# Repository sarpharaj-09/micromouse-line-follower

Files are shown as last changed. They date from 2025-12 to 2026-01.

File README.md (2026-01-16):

# Micromouse Line Follower

 **Project Status: In Development** 

A line-following micromouse robot project combining hardware design (KiCAD PCB layouts) with firmware development. This repository includes both Arduino Nano and ESP32 implementations, with comprehensive testing code and calibration tools.

## Overview

This project aims to build a reliable line-following robot using:
- **QTR-8 sensor array** for line detection
- **TB6612FNG motor driver** for motor control
- **Maze solving algorithm** with path simplification
- **PID control** for stable line following
- Dual MCU support: **ESP32** (primary) and **Arduino Nano** (testing)

The firmware includes motor control, PID tuning, sensor calibration, and a maze-solving algorithm that records and simplifies paths.

## Hardware

### Microcontrollers
- **ESP32 Development Board** (primary target)
- **Arduino Nano** (for testing and prototyping)

### Components
- **Motor Driver**: TB6612FNG
- **Line Sensors**: QTR-8 analog/RC sensor array
- **Motors**: DC motors for wheels
- **Power**: Battery pack
- **Display**: DM-OLED096 (0.96" OLED) - in design
- **Miscellaneous**: Jumper wires, resistors, capacitors

## Project Structure

```
micromouse-line-follower/
 Arduino_Nano/               # Arduino Nano PCB design (KiCAD)
    pcb_v1/                # Version 1 PCB layout
        DM-OLED096-636/    # OLED display footprint & symbol
        ESP32-DEVKIT-V1/   # ESP32 footprint & symbol
        MP1584_buck/       # Buck converter module
        kikad_dsign.*      # KiCAD project files
 ESP32/                      # ESP32 PCB design (KiCAD)
    pcb_v1/                # Version 1 PCB layout
        DM-OLED096-636/    # OLED display footprint & symbol
        ESP32-DEVKIT-V1/   # ESP32 footprint & symbol
        lineMazeSolver.*   # KiCAD project files
 micromouse_v1/             # Main firmware project (PlatformIO)
    micromouse_v1/
        platformio.ini     # PlatformIO configuration
        include/           # Header files
        lib/               # Dependencies (QTRSensors, TB6612FNG)
        src/
           main.cpp       # Main firmware with maze solving & PID
        test/              # Unit tests
 testing_phase_code/        # Standalone test sketches
    ESP32_test_code/       # ESP32-specific tests
       qtrSensor.ino     # QTR sensor test
    Nano_test_code/        # Arduino Nano tests
        Moter_test/        # Motor driver tests
        PID_Bluethooth/    # Bluetooth PID tuning
        plotter/           # Serial plotter data
        QTR_test/          # QTR sensor calibration
 README.md
```

## Firmware Features

### Current Implementation (main.cpp)
- **8-channel QTR sensor** integration with calibration
- **PID-based line following** with configurable gains (Kp, Kd)
- **Maze solving algorithm** with wall detection and path recording
- **Path simplification** to optimize shortest route
- **Motor control** with variable speed and direction
- **Turn decision logic** (left, straight, right)

### Pin Configuration (Arduino Nano)
```
Motor Control:
  - Motor 1: AIN1=4, AIN2=5, PWMA=3
  - Motor 2: BIN1=8, BIN2=9, PWMB=6
Control:
  - Switches: SW1=10, SW2=11, SW3=12
  - LED: 7
```

## Getting Started

### Prerequisites

- [PlatformIO](https://platformio.org/) (for ESP32 development)
- [Arduino IDE](https://www.arduino.cc/en/software) (for Nano sketches)
- Required libraries:
  - `SparkFun_TB6612` (Motor Driver)
  - `QTRSensors` (Line Sensor Array)

### Building & Uploading (PlatformIO/ESP32)

```powershell
cd micromouse_v1/micromouse_v1
pio run              # Build
pio run -t upload    # Upload to connected ESP32
```

### Testing (Arduino Nano)

1. Open Arduino IDE
2. Load a test sketch: `testing_phase_code/Nano_test_code/<test_folder>/<sketch>.ino`
3. Install dependencies via Library Manager
4. Select board (Arduino Nano) and COM port
5. Upload

### Test Sketches Available

| Sketch | Purpose |
|---|---|
| `Moter_test` | Test TB6612 motor driver (forward, backward, turn) |
| `QTR_test` | Read raw QTR sensor values and calibrate |
| `PID_Bluethooth` | Wireless PID tuning via Bluetooth serial |
| `plotter` | Stream sensor data for Serial Plotter visualization |

## Development Workflow

- **Feature branches**: Use `wip/*` prefix for work-in-progress branches
- **Main branch**: Keep stable with tested, documented commits
- **Testing**: Validate on both hardware and in simulation before merging
- **Documentation**: Update this README and code comments when adding features

## PCB Design Status

- **Arduino Nano v1**: In design phase - includes OLED display, buck converter
- **ESP32 v1**: In design phase - primary development board layout

## Troubleshooting

### Sensor Calibration Issues
- Run `QTR_test` to verify raw sensor values
- Check sensor array alignment over the line
- Verify power supply voltage (QTR operates 3.3-5V)

### Motor Control Issues
- Use `Moter_test` to verify TB6612 pin connections
- Check PWM pins are available on your MCU
- Verify motor power supply is adequate

### PID Tuning
- Use `PID_Bluethooth` for real-time parameter adjustment
- Start with low Kp/Kd values and increase gradually
- Monitor motor oscillation and response time

## Contributing

Contributions welcome! Please:
1. Create a feature branch (`wip/feature-name`)
2. Test thoroughly on hardware
3. Submit a pull request with clear description
4. Update documentation as needed

## License

This project is licensed under the terms specified in `LICENSE`.

---

**Last Updated**: January 2026  
**Note**: This project is actively developed. Features and documentation are updated frequently.

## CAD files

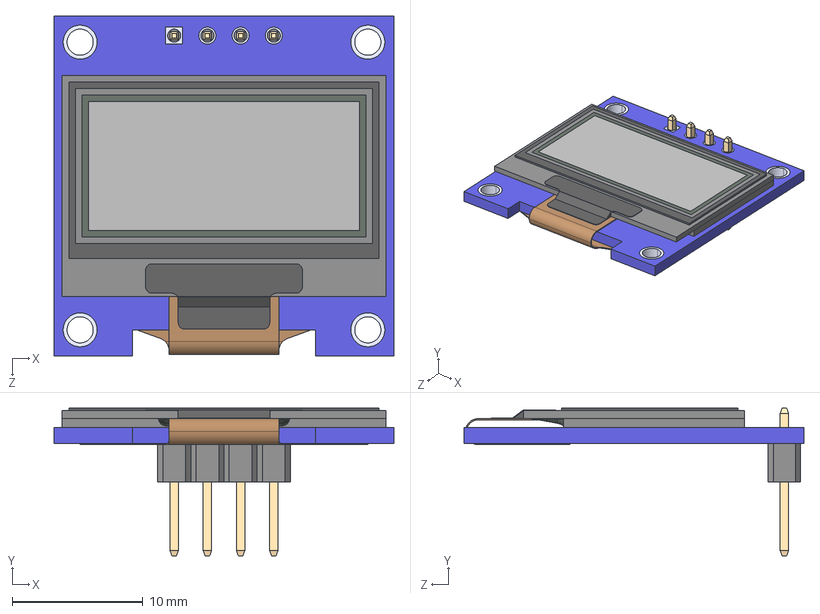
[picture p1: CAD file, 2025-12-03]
Arduino_Nano/pcb_v1/DM-OLED096-636--3DModel-STEP-56544.STEP
26.0 x 11.3 x 26.0 mm
DM-OLED096-636_Module
DM-OLED096-636_Panel

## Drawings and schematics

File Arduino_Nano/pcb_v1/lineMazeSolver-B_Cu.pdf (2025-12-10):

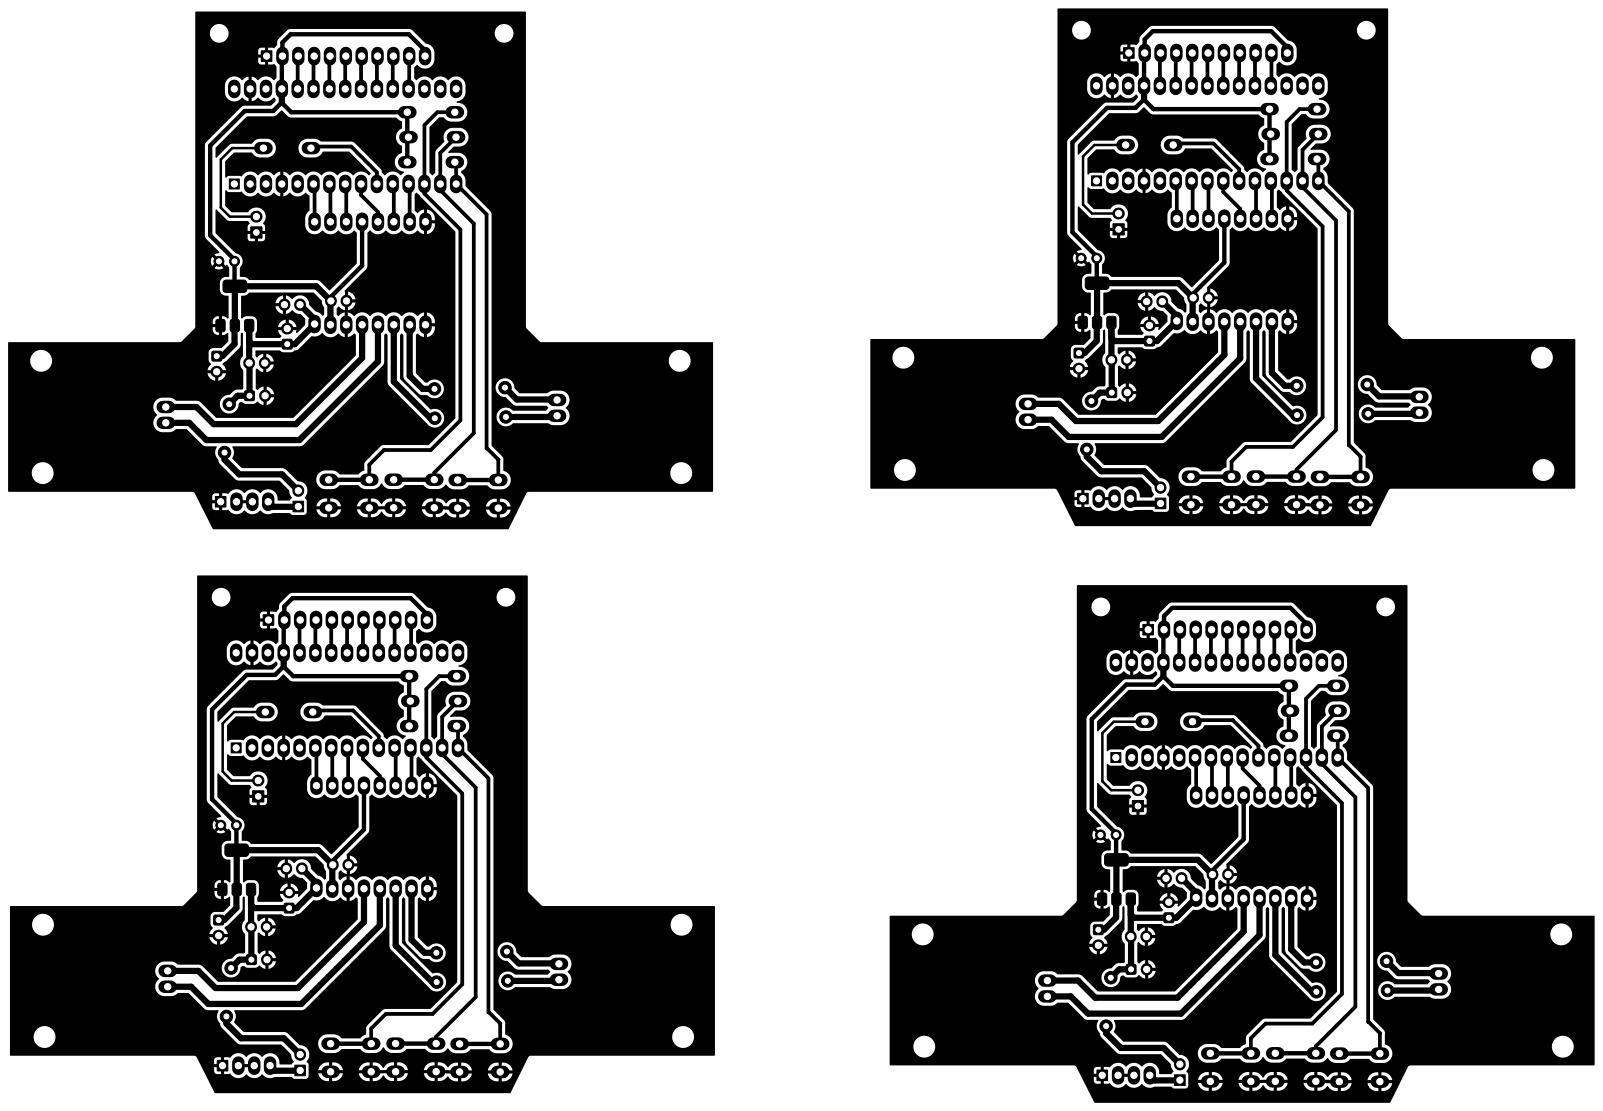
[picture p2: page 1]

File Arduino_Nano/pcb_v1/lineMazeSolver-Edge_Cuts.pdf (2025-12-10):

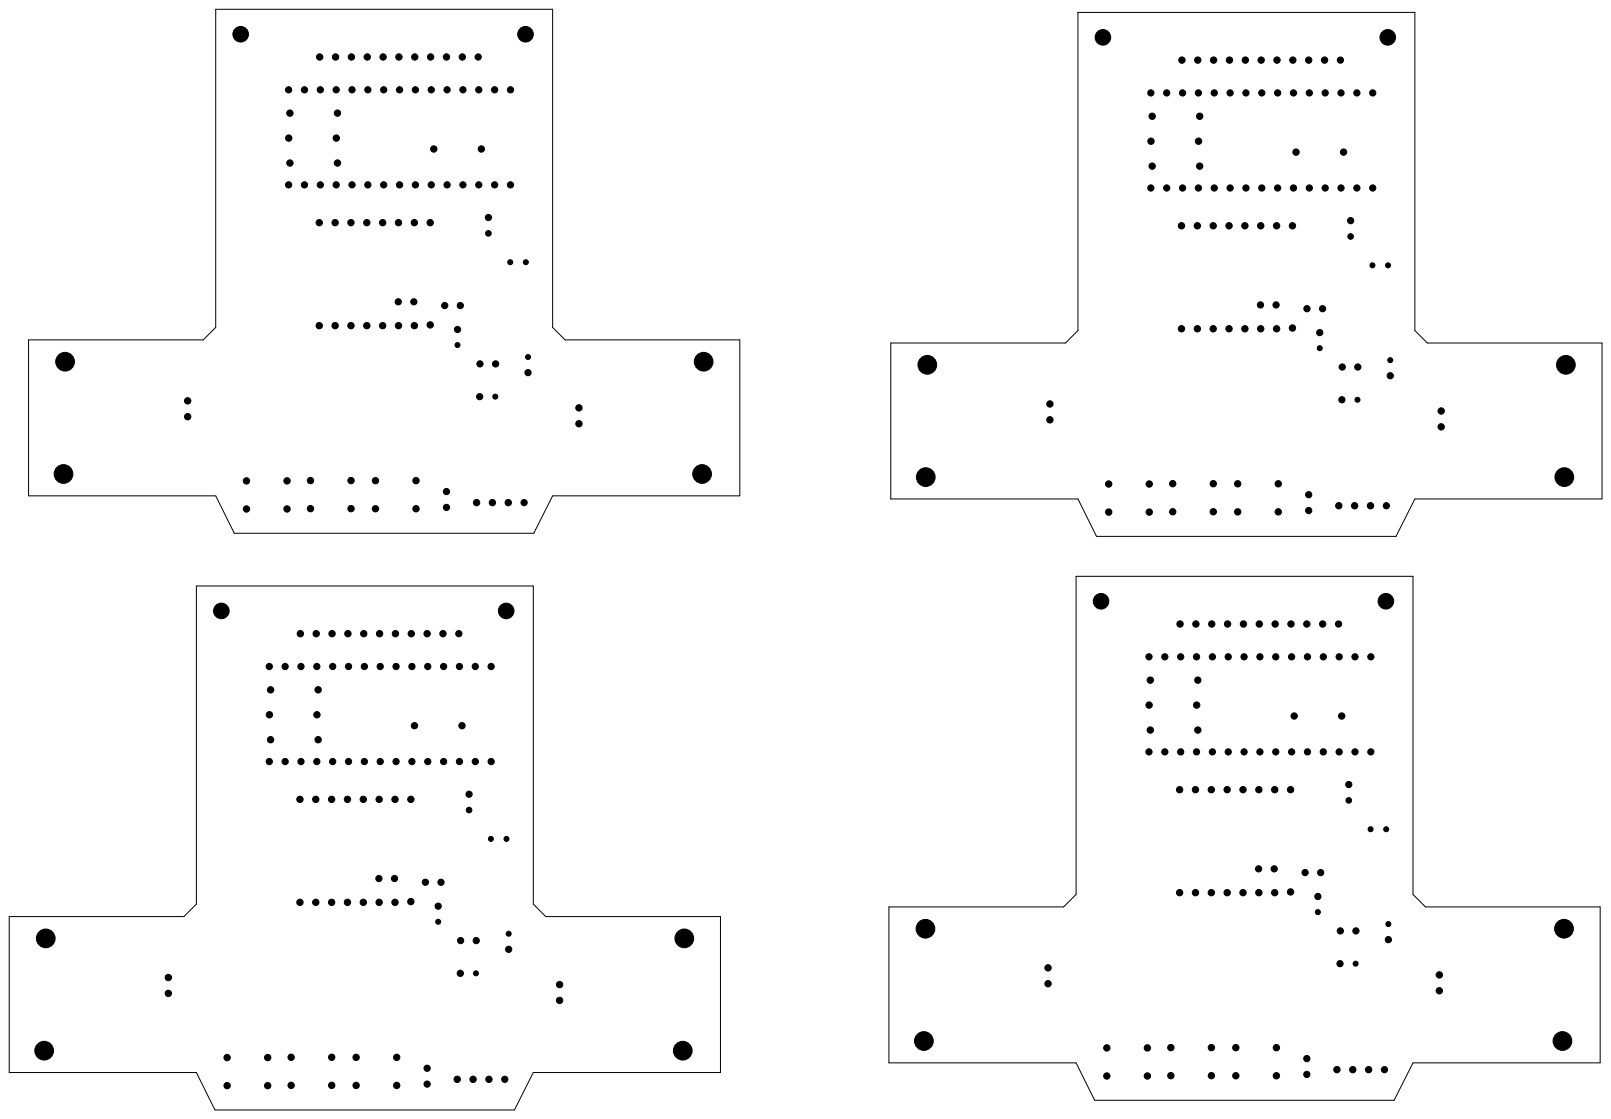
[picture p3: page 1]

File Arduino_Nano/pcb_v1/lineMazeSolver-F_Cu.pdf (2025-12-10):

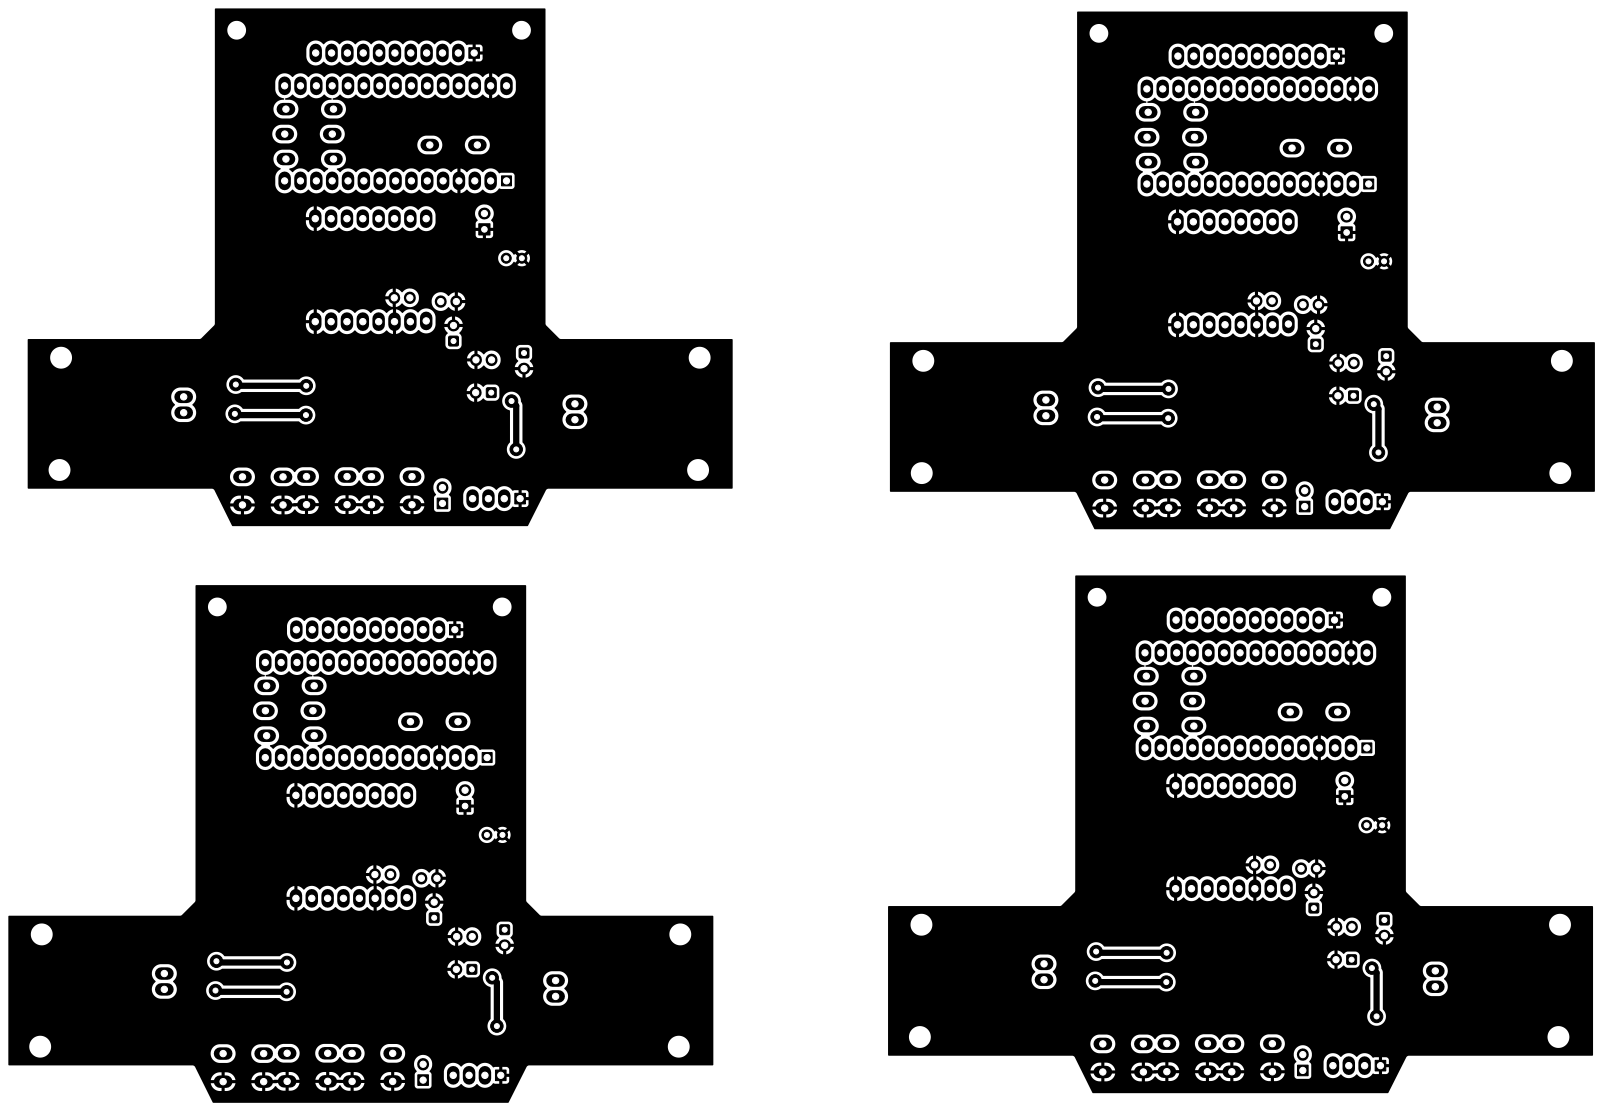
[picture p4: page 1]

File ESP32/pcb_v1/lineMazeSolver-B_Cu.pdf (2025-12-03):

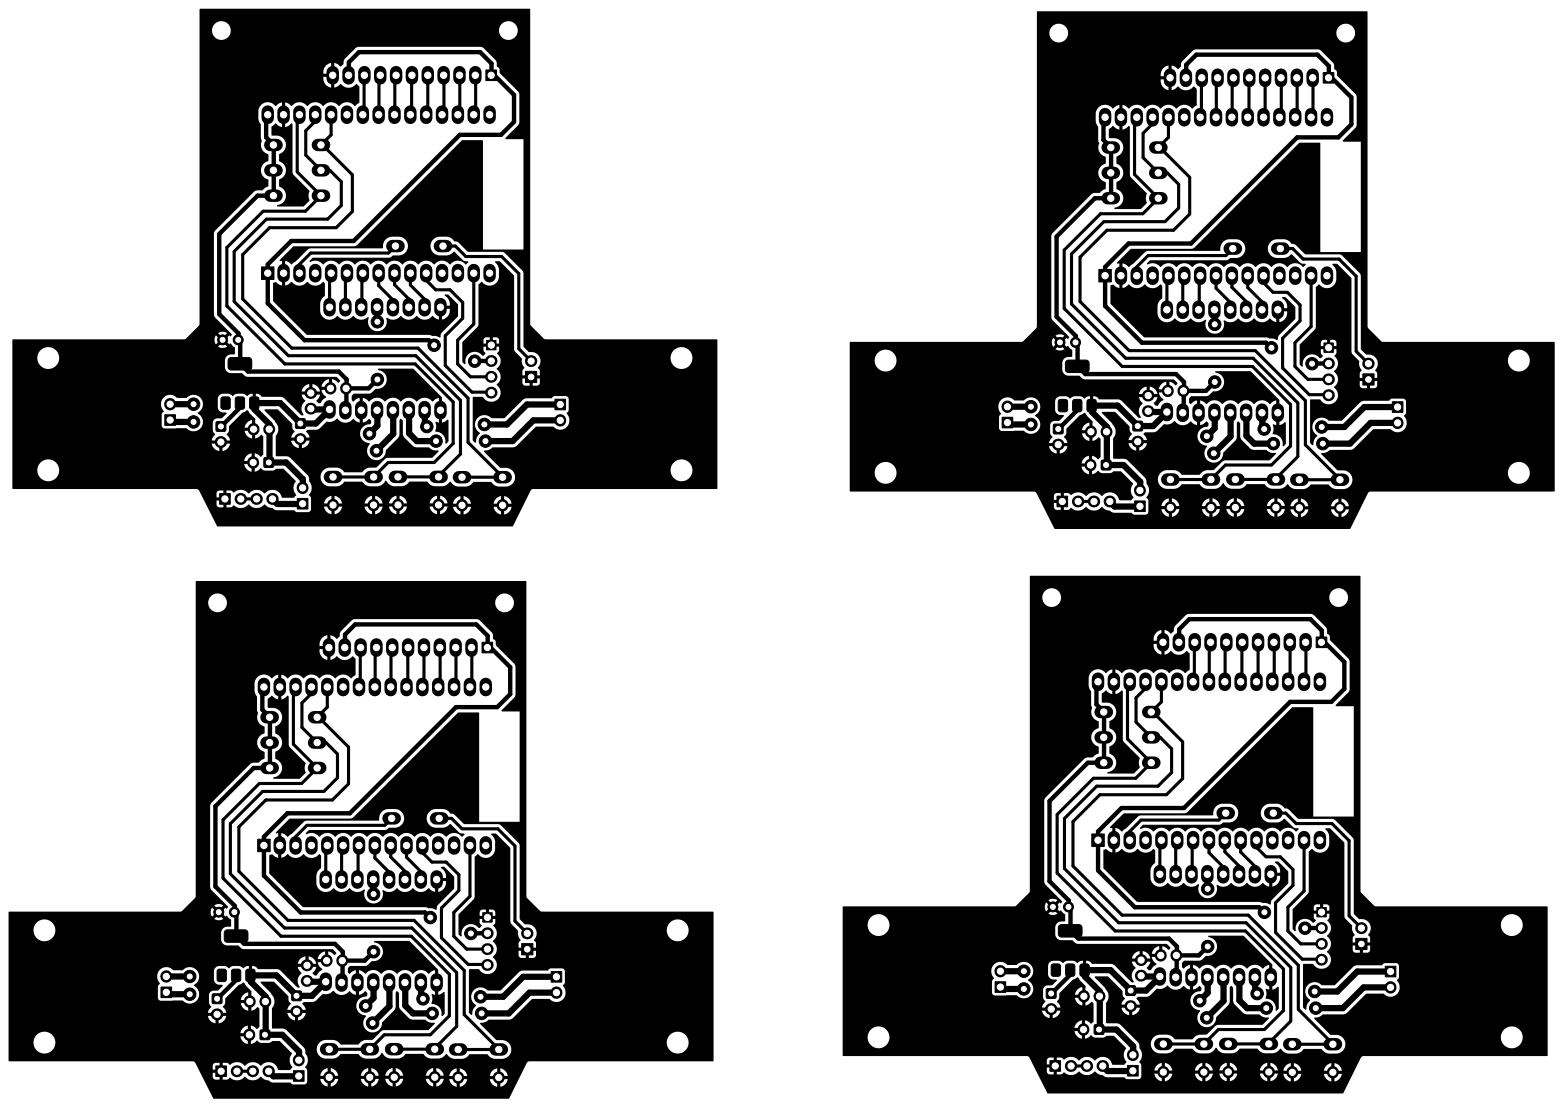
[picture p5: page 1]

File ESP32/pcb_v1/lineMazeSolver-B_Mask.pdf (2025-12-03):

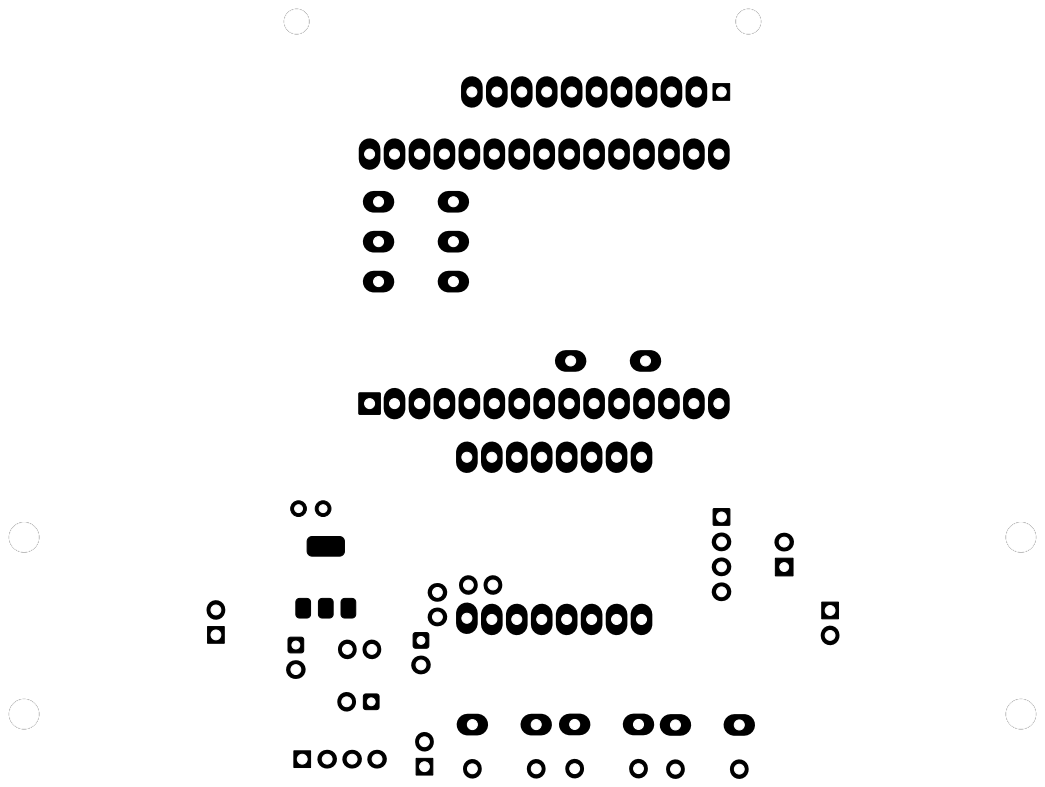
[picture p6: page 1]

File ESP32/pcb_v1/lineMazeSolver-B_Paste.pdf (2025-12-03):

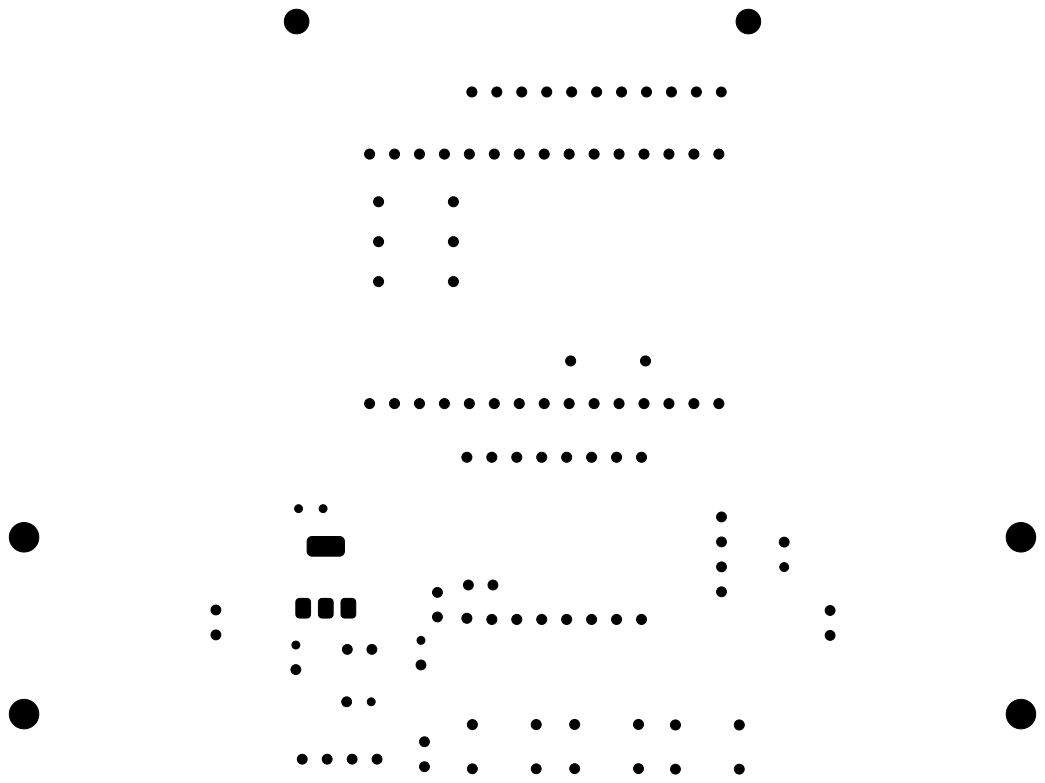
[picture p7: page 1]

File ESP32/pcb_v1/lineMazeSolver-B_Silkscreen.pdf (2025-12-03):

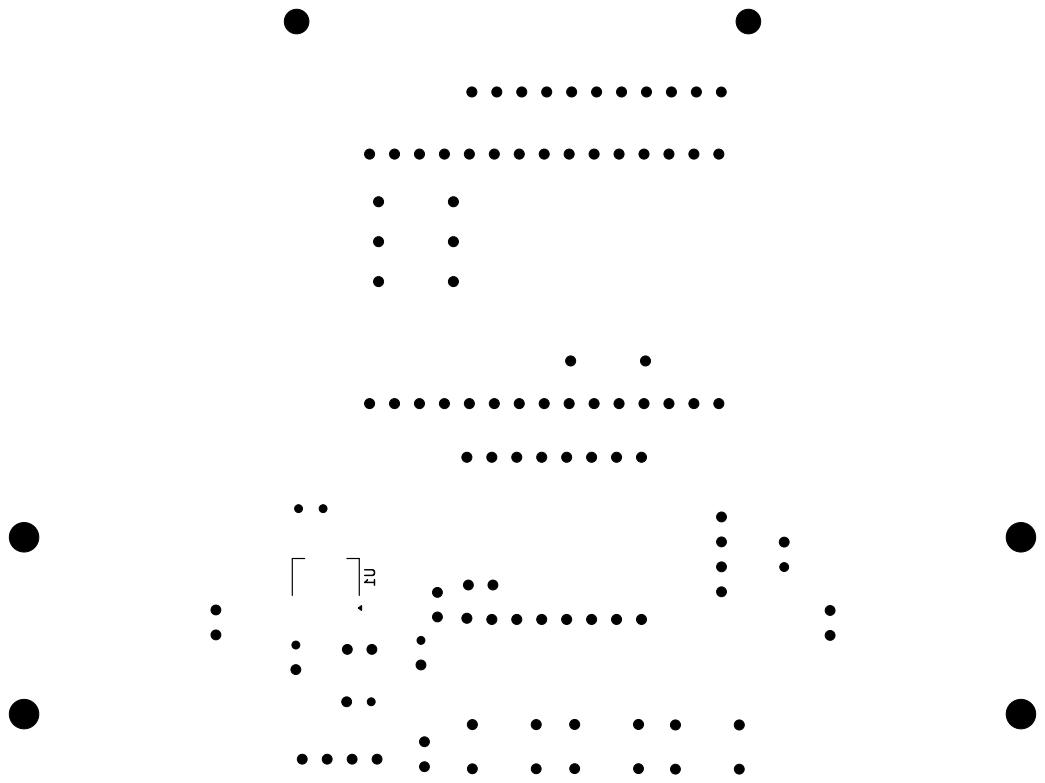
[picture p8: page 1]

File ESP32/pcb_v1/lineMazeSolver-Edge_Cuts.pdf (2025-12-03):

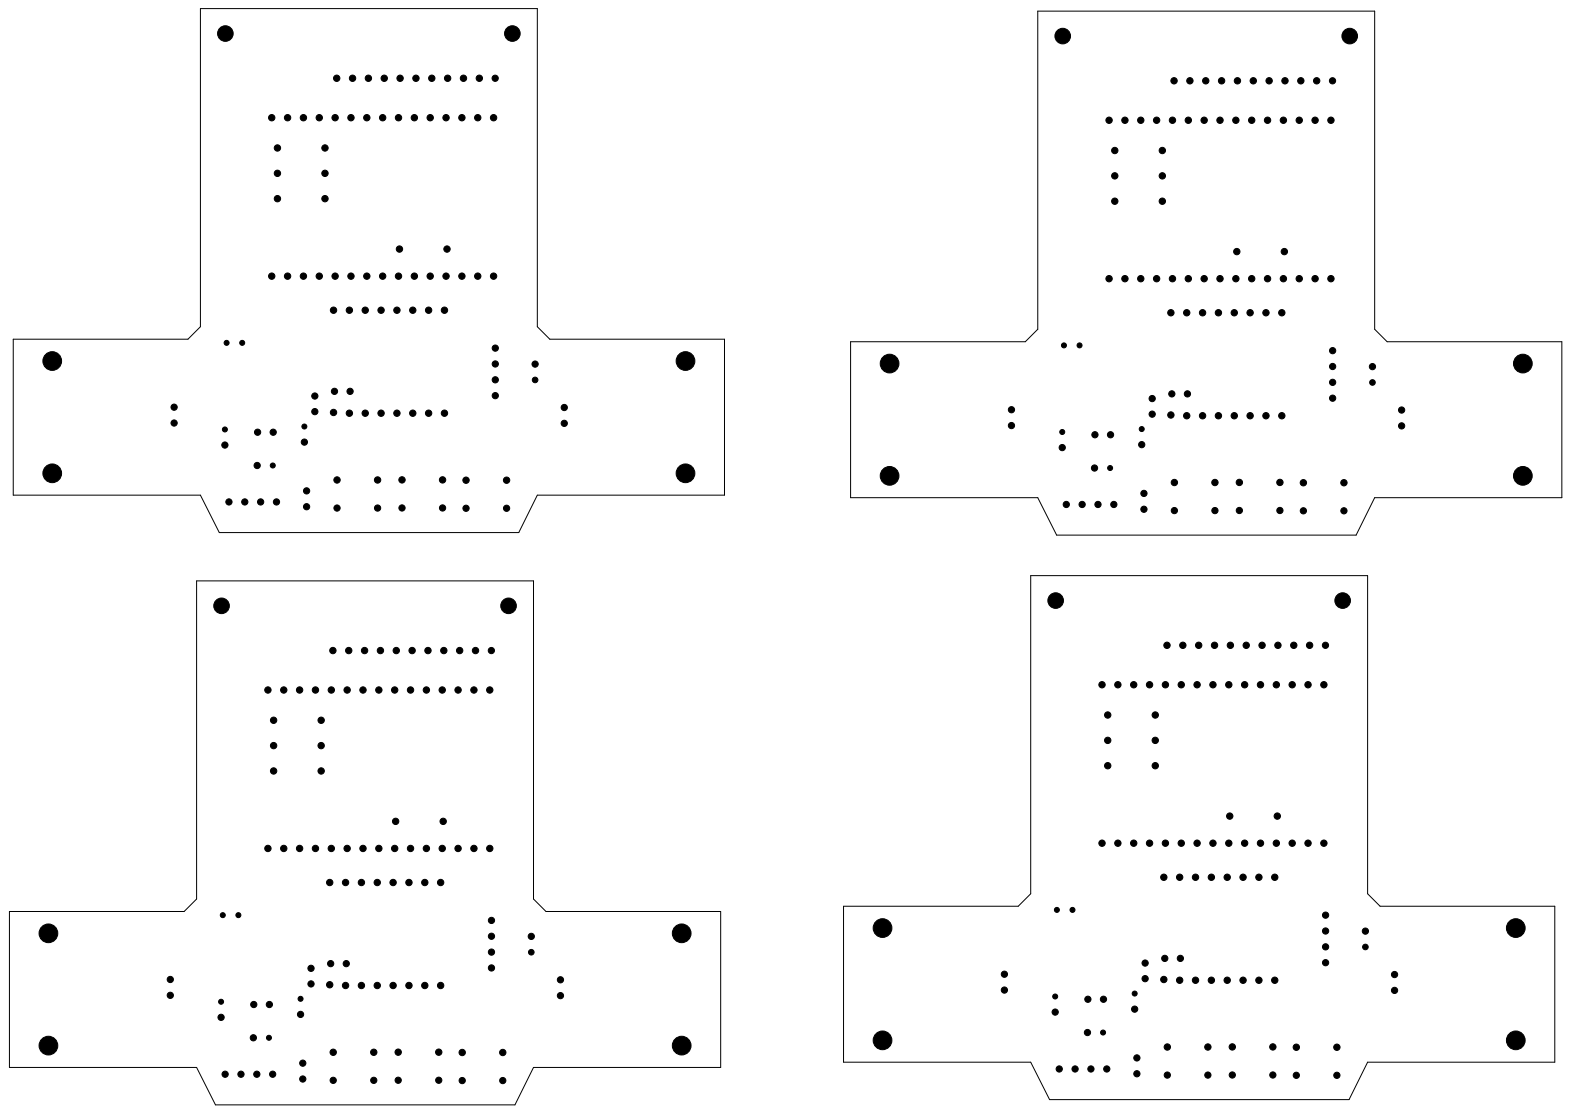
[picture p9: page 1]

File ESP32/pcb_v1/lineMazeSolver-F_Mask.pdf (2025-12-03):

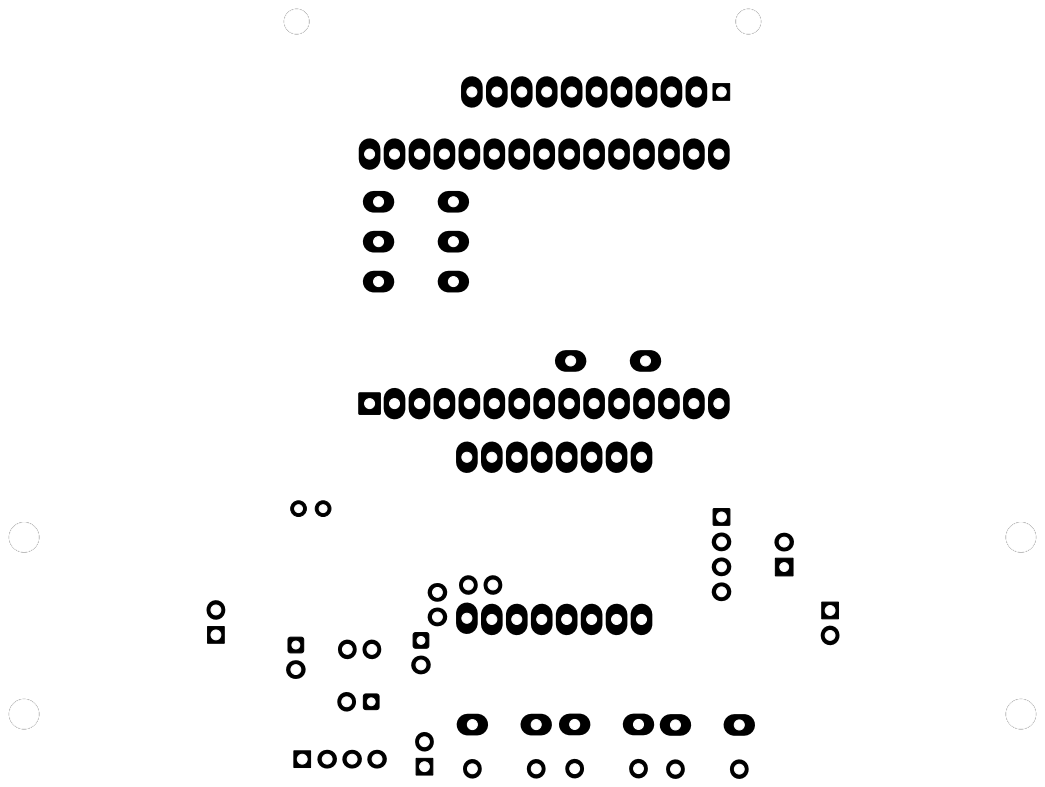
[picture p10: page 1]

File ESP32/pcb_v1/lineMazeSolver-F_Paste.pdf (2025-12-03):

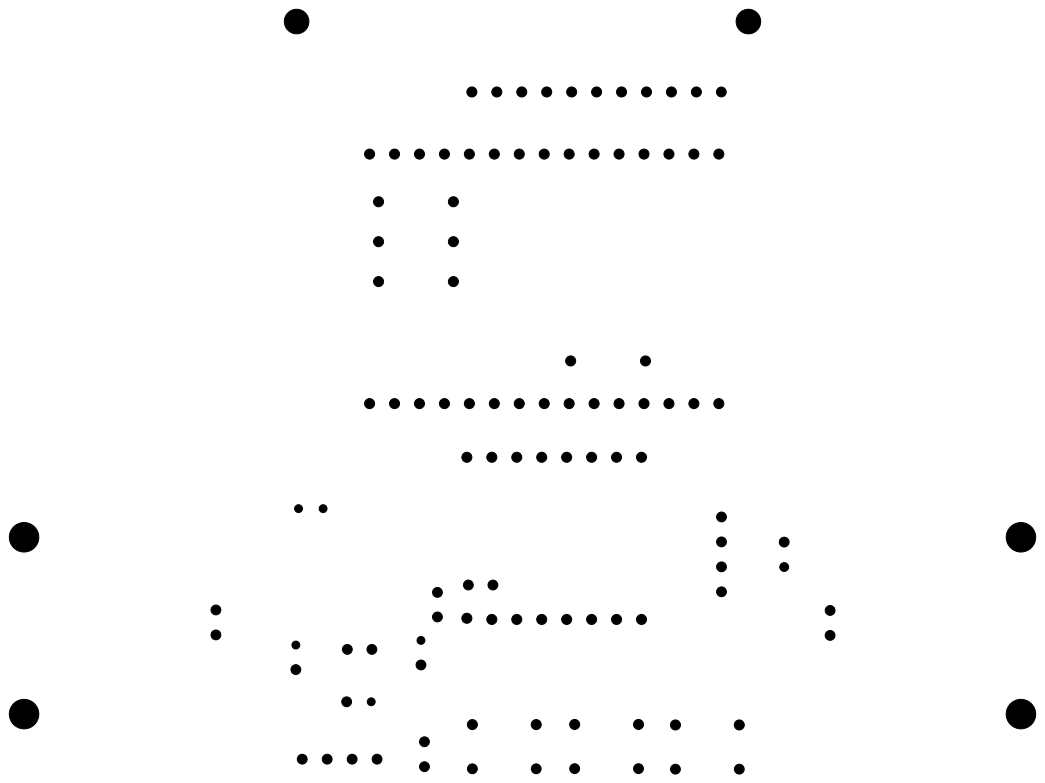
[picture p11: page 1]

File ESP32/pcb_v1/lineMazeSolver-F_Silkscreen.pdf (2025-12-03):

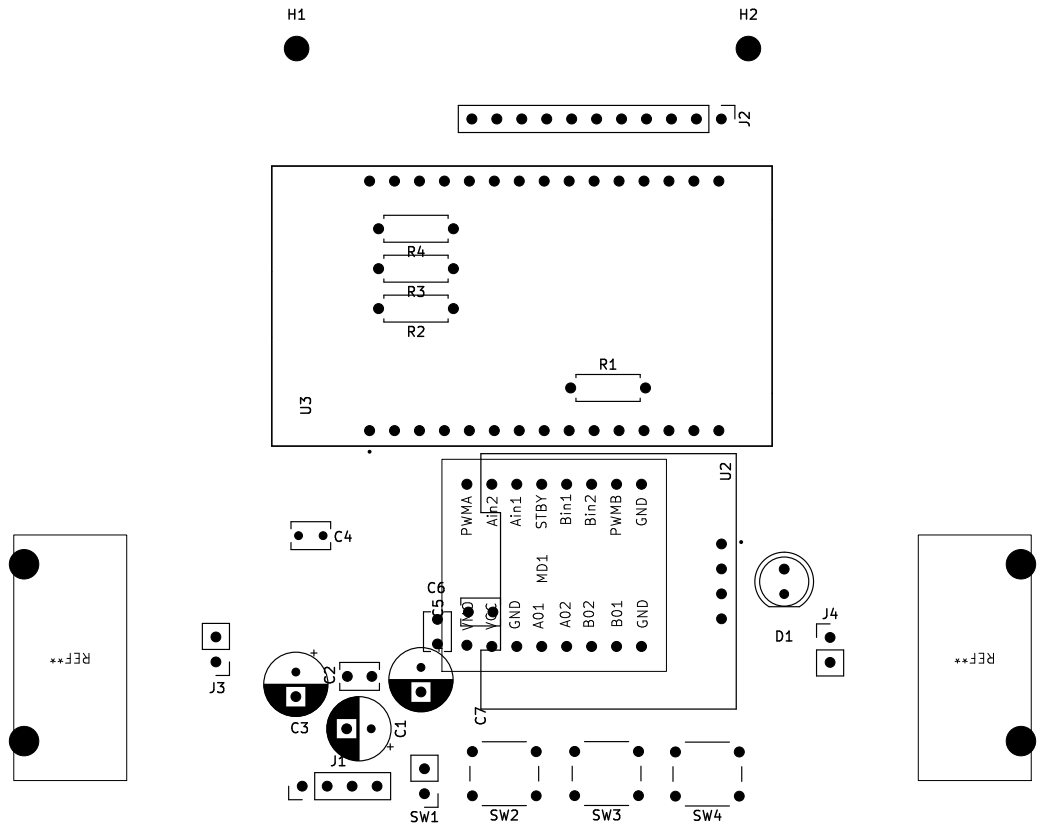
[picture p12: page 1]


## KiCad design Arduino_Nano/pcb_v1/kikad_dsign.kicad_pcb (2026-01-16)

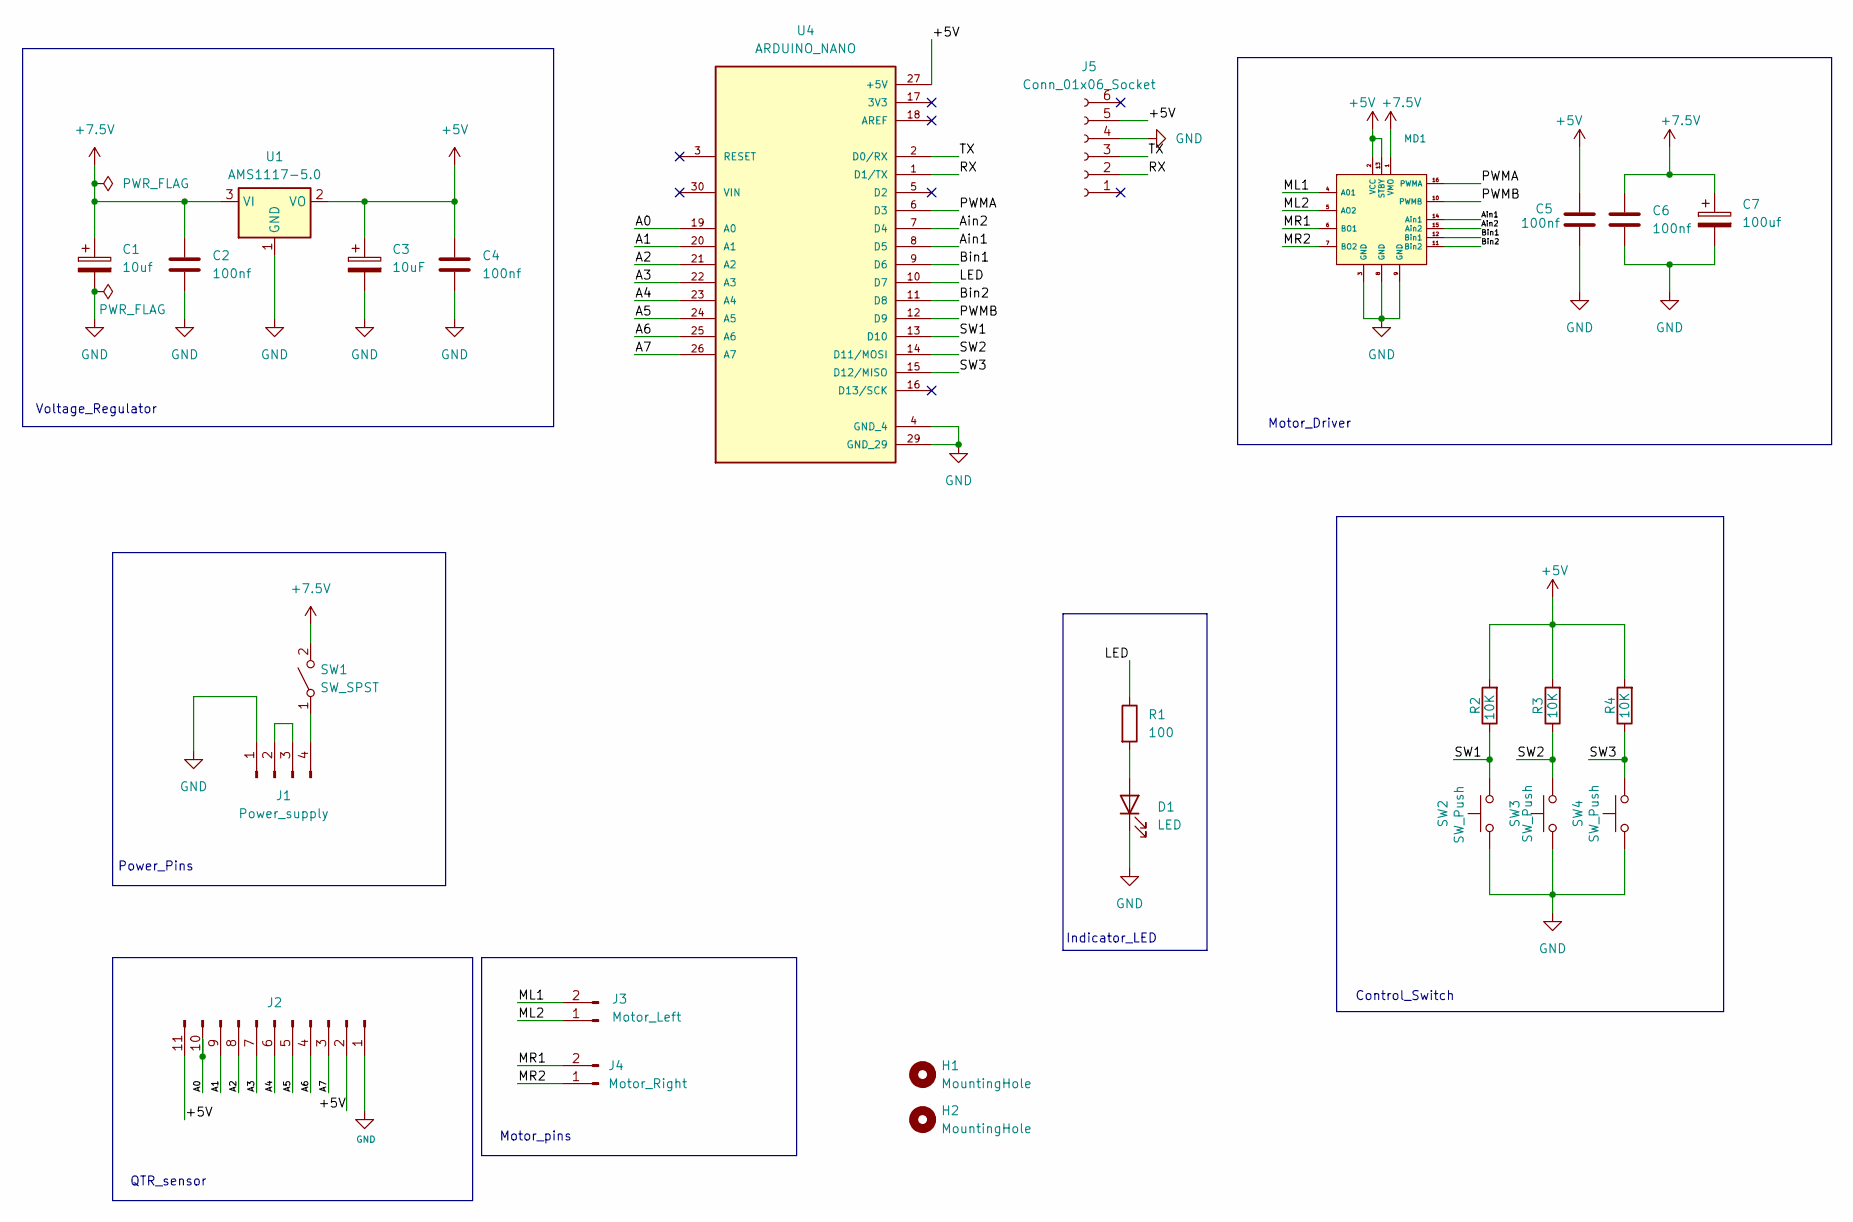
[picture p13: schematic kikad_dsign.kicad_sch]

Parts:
C1: 10uf; CP_Radial_D6.3mm_P2.50mm
C2, C4, C5, C6: 100nf; C_Disc_D3.8mm_W2.6mm_P2.50mm
C3: 10uF; CP_Radial_D6.3mm_P2.50mm
C7: 100uf; CP_Radial_D6.3mm_P2.50mm
D1: LED; LED_D5.0mm
H1, H2: MountingHole; MountingHole_2.5mm
J1: Power_supply; PinHeader_1x04_P2.54mm_Vertical
J2: Conn_01x11_Pin; PinHeader_1x11_P2.54mm_Vertical
J3: Motor_Left; PinHeader_1x02_P2.54mm_Vertical
J4: Motor_Right; PinHeader_1x02_P2.54mm_Vertical
J5: Conn_01x06_Socket
MD1: tbfng motor driver
R1: 100; R_Axial_DIN0207_L6.3mm_D2.5mm_P7.62mm_Horizontal
R2, R3, R4: 10K; R_Axial_DIN0207_L6.3mm_D2.5mm_P7.62mm_Horizontal
SW1: SW_SPST; PinHeader_1x02_P2.54mm_Vertical
SW2, SW3, SW4: SW_Push; SW_PUSH_6mm
U1: AMS1117-5.0; SOT-223-3_TabPin2
U4: ARDUINO_NANO; Arduino_Nano; PARTREV 30/06/2021

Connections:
+5V: C3.1, C4.1, C5.2, J2.2, J2.11, J5.5, MD1.2 (VCC), MD1.13 (STBY), R2.2, R3.2, R4.2, U1.2 (VO), U4.27 (+5V)
+7.5V: C1.1, C2.1, C6.1, C7.1, MD1.1 (VMO), SW1.2 (B), U1.3 (VI)
/A0: J2.10, U4.19 (A0)
/A1: J2.9, U4.20 (A1)
/A2: J2.8, U4.21 (A2)
/A3: J2.7, U4.22 (A3)
/A4: J2.6, U4.23 (A4)
/A5: J2.5, U4.24 (A5)
/A6: J2.4, U4.25 (A6)
/A7: J2.3, U4.26 (A7)
/Ain1: MD1.14 (Ain1), U4.8 (D5)
/Ain2: MD1.15 (Ain2), U4.7 (D4)
/Bin1: MD1.12 (Bin1), U4.9 (D6)
/Bin2: MD1.11 (Bin2), U4.11 (D8)
/LED: R1.1, U4.10 (D7)
/ML1: J3.2, MD1.4 (A01)
/ML2: J3.1, MD1.5 (AO2)
/MR1: J4.2, MD1.6 (BO1)
/MR2: J4.1, MD1.7 (BO2)
/PWMA: MD1.16 (PWMA), U4.6 (D3)
/PWMB: MD1.10 (PWMB), U4.12 (D9)
/RX: J5.2, U4.1 (D1/TX)
/SW1: R2.1, SW2.2, U4.13 (D10)
/SW2: R3.1, SW3.2, U4.14 (D11/MOSI)
/SW3: R4.1, SW4.2, U4.15 (D12/MISO)
/TX: J5.3, U4.2 (D0/RX)
GND: C1.2, C2.2, C3.2, C4.2, C5.1, C6.2, C7.2, D1.1 (K), J1.1, J2.1, J5.4, MD1.3 (GND), MD1.8 (GND), MD1.9 (GND), SW2.1, SW3.1, SW4.1, U1.1 (GND), U4.4 (GND_4), U4.29 (GND_29)
unnamed: D1.2 (A), R1.2
unnamed: J1.2, J1.3
unnamed: J1.4, SW1.1 (A)

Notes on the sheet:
Motor_Driver
QTR_sensor
Power_Pins
Motor_pins
Voltage_Regulator
Indicator_LED
Control_Switch

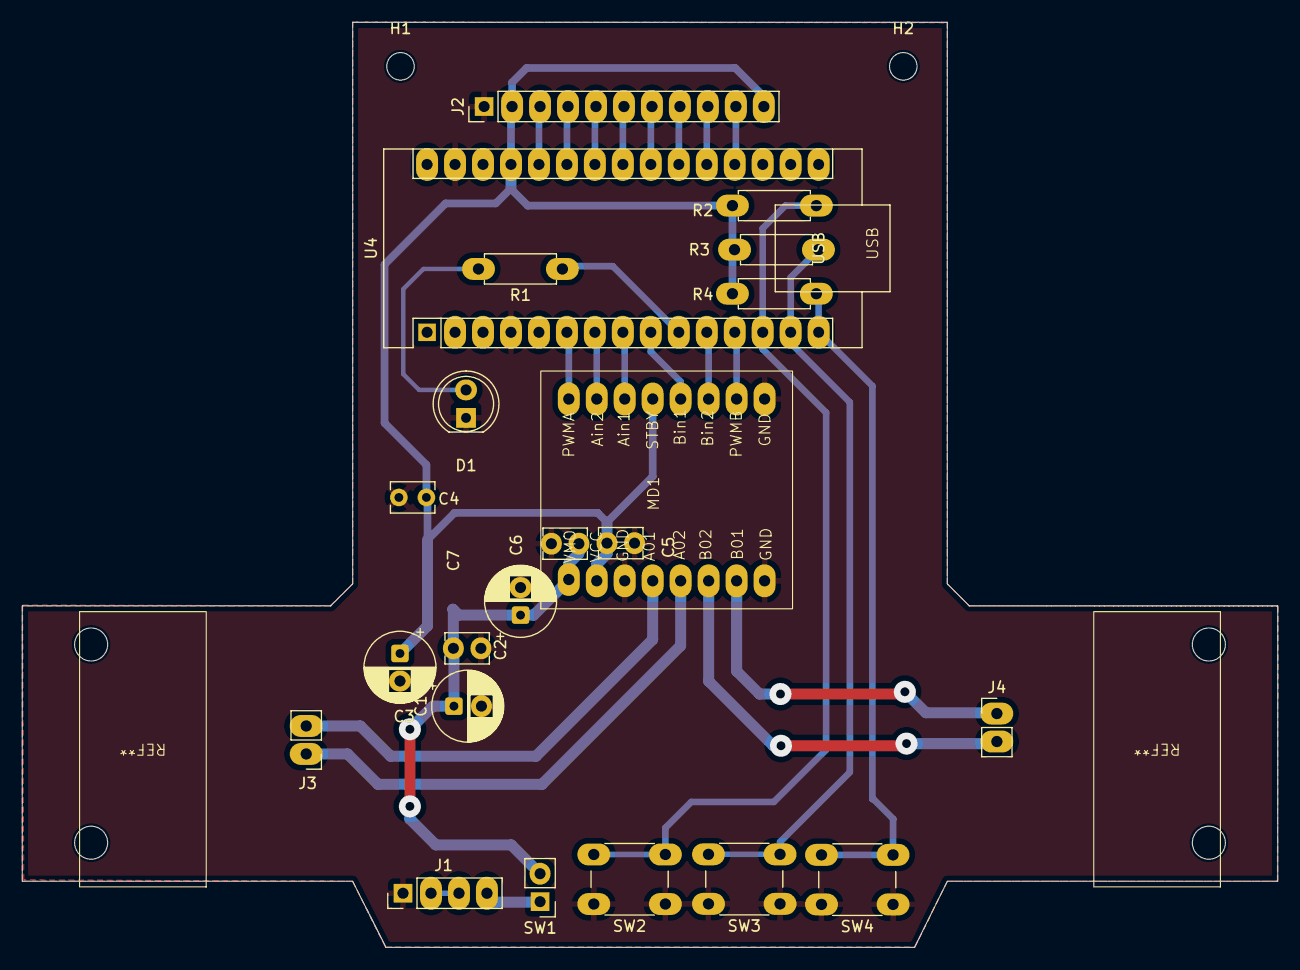
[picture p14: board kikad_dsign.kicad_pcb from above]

Board: 2 copper layers, 114.0 x 84.0 mm, 25 parts (1 on the bottom side), 28 nets.

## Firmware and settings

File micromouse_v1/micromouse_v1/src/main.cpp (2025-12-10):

#include <SparkFun_TB6612.h>  // This library is for SparkFun motor driver  
#include <QTRSensors.h>       // It is for QTR sensors 

// Motor pin definitions
#define AIN1 4
#define BIN1 8
#define AIN2 5
#define BIN2 9
#define PWMA 3
#define PWMB 6
// Control switches and LED
#define sw1 10
#define sw2 11
#define sw3 12 
#define led 7

int s1, s2, s3;
char dir;
int chr = 1;

// Sensor configuration
#define NUM_SENSORS 8
uint16_t sensors1[NUM_SENSORS];
uint16_t thr[NUM_SENSORS];

// PID parameters
#define MaxSpeed 130
#define BaseSpeed 130
int lastError = 0;
float kp = 0.161;    // Proportional gain - tune based on your bot
float kd = 0.8;      // Derivative gain - tune based on your bot
// Shortest path parameters
char path[100];
int path_length = 0;

// Creating motor and sensor instances
Motor motor1 = Motor(AIN1, AIN2, PWMA, 1, 1); 
Motor motor2 = Motor(BIN1, BIN2, PWMB, 1, 1);
QTRSensors qtra;

void calibration();
void follow_segment();
void maze();
void turn(char dir);
void simplify_path();
char select_turnL(char found_left, char found_straight, char found_right);
char select_turnR(char found_right, char found_straight, char found_left);
void follow_segment1();
void follow_segment2();
void follow_segment3();

void setup()
{
  qtra.setTypeAnalog();
  qtra.setSensorPins((const uint8_t[]) {   // QTR8A sensor setup
    A7, A6, A5, A4, A3, A2, A1, A0
  }, NUM_SENSORS);

  pinMode(sw1, INPUT);
  pinMode(sw2, INPUT);
  pinMode(sw3, INPUT);
  pinMode(led, OUTPUT);     // Control pin setup

  Serial.begin(9600);
  // while (!Serial)
  // {
  //   ;                           //Serial communication setup for bluetooth
  // }
  s1 = digitalRead(sw1);
  while (s1 == HIGH)
  {
    s1 = digitalRead(sw1);      // Calibration phase - bot gets calibrated after pressing sw1
  }
  digitalWrite(led, HIGH);
  delay(800);
  calibration();
  s2 = digitalRead(sw2);
  while (s2 == HIGH)
  {
    s2 = digitalRead(sw2);      // Press sw2 to start the bot and follow the path
  }
  delay(800);
}

void loop() {
  forward(motor1, motor2, 30);
  delay(40);
  forward(motor1, motor2, 40);
  delay(40);                              // Gradually increase speed to avoid sudden acceleration
  forward(motor1, motor2, 60);
  delay(40);
  maze();
}

void calibration()
{
  // Calibration cycle - swing left and right to read sensor values
  for (int i = 0; i <= 100; i++)
  {
    if (i < 25 || i >= 75)
    {
      left(motor1, motor2, 170);   // Left turn
    }
    else
    {
      right(motor1, motor2, 170);  // Right turn
    }
    qtra.calibrate();
    delay(10);
  }
  
  brake(motor1, motor2);
  for (int i = 0; i < NUM_SENSORS; i++)
  {
    Serial.print(qtra.calibrationOn.minimum[i]);
    Serial.print(' ');
    thr[i] = (qtra.calibrationOn.minimum[i] + qtra.calibrationOn.maximum[i]) / 2;
    // Calculating the threshold value for making the decision above thr black line and below white line
  }

  Serial.println();
  for (int i = 0; i < NUM_SENSORS; i++)
  {
    Serial.print(qtra.calibrationOn.maximum[i]);
    Serial.print(' ');
  }
  Serial.println();
  Serial.print("Threshold[0]: ");
  Serial.println(thr[0]);
  Serial.print("Threshold[7]: ");
  Serial.println(thr[7]);
}
void follow_segment()
{
  while (1)
  {
    digitalWrite(led, LOW);
    // For BLACK line, use readLineBlack() instead of readLineWhite()
    int position = qtra.readLineWhite(sensors1);   // Get current position on line
    int error = 3500 - position;  // 3500 is center position
    int motorSpeed = kp * error + kd * (error - lastError);
    lastError = error;
    int rightMotorSpeed = BaseSpeed - motorSpeed;
    int leftMotorSpeed = BaseSpeed + motorSpeed;
    if (rightMotorSpeed > MaxSpeed) rightMotorSpeed = MaxSpeed;
    if (leftMotorSpeed > MaxSpeed) leftMotorSpeed = MaxSpeed;
    if (rightMotorSpeed < 0) rightMotorSpeed = 0;
    if (leftMotorSpeed < 0) leftMotorSpeed = 0;
    motor1.drive(rightMotorSpeed);
    motor2.drive(leftMotorSpeed);
    
    if ((sensors1[0] < thr[0]) || (sensors1[7] < thr[7]))
    {
      return;
      // Found an intersection.
    }
    else if (sensors1[1] > thr[1] && sensors1[2] > thr[2] && sensors1[3] > thr[3] && sensors1[4] > thr[4] && sensors1[5] > thr[5] && sensors1[6] > thr[6])
    {
      // There is no line visible ahead, and we didn't see any
      // intersection. Must be a dead end.
      return;
    }
    delay(5);
  }
}
void maze()
{
  while (1)
  {
    follow_segment(); // Follow path until an intersection is detected
    digitalWrite(led, HIGH);
    brake(motor1,motor2);
    forward(motor1, motor2, 50);
    delay(150);
    brake(motor1, motor2);
    // These variables record whether the robot detected a line to the
    // left, straight, or right while examining the current intersection
    unsigned char found_left = 0;
    unsigned char found_straight = 0;
    unsigned char found_right = 0;
    
    // Read sensors and check intersection type
    qtra.readLineWhite(sensors1);
    
    if (sensors1[0] < thr[0])
    {
      found_left = 1;
    }
    if (sensors1[7] < thr[7])
    {
      found_right = 1;
    }
    // Drive straight a bit more - this is enough to line up our
    //wheels with the intersection.
    forward(motor1, motor2, 50);
    delay(50);
    brake(motor1, motor2);
    delay(100);

    qtra.readLineWhite(sensors1);
    if (sensors1[1] < thr[1] || sensors1[2] < thr[2] || sensors1[3] < thr[3] || sensors1[4] < thr[4] || sensors1[5] < thr[5] || sensors1[6] < thr[6] )
    {
      found_straight = 1;
    }
    // Check for the ending spot.
    if (sensors1[1] < thr[1] && sensors1[2] < thr[2] && sensors1[3] < thr[3] && 
        sensors1[4] < thr[4] && sensors1[5] < thr[5] && sensors1[6] < thr[6])
      break;  // End point detected - all middle sensors on black
      
    // Decide which turn to take based on the selected rule
    if (chr == 1)
      dir = select_turnL(found_left, found_straight, found_right);
    else if (chr == 2)
      dir = select_turnR(found_right, found_straight, found_left);
    // Serial.println(dir);
    // Take a turn according to that
    turn(dir);
    // Store the intersection in the path variable.
    path[path_length] = dir;
    path_length++;
    // Simplify the path for the final run
    simplify_path();
  }
  // Second run: execute the optimized shortest path
  brake(motor1, motor2);
  forward(motor1, motor2, 80);
  delay(400);                   // Move straight at end point and turn on LED
  brake(motor1, motor2);
  for (int w = 0; w < path_length; w++)
  {
    Serial.print(path[w]);
    Serial.print(' ');
  }
  digitalWrite(led, HIGH);
  delay(4000);
  digitalWrite(led, LOW);
  s2 = digitalRead(sw2);
  while (s2 == HIGH)
  {
    s2 = digitalRead(sw2);     // Wait for pressing a switch
  }
  delay(800);
  forward(motor1, motor2, 60);
  delay(40);
  forward(motor1, motor2, 80);
  delay(40);
  forward(motor1, motor2, 100);
  delay(40);
  while (1)
  {
    int k;
    for (k = 0; k < path_length; k++)
    {
      follow_segment();
      forward(motor1, motor2, 50);    // After reaching a intercetion follow the shortest path turn
      delay(50);
      forward(motor1, motor2, 60);
      delay(200);
      brake(motor1, motor2);
      delay(5);
      turn(path[k]);
    }
    follow_segment();
    brake(motor1, motor2);
    forward(motor1, motor2, 80);
    delay(400);
    brake(motor1, motor2);
    digitalWrite(led, HIGH);
    delay(4000);
    digitalWrite(led, LOW);
  }
  // Go back to a starting of the main loop
}
char select_turnL(char found_left, char found_straight, char found_right)
{
  // Make a decision about how to turn. The following code
  // implements a left-hand-on-the-wall strategy, where we always prefer left turns
  if (found_left)
    return 'L';
  else if (found_straight)
    return 'S';
  else if (found_right)
    return 'R';
  else
    return 'B';
}
char select_turnR(char found_right, char found_straight, char found_left)
{
  // Make a decision about how to turn. The following code
  // implements a right-hand-on-the-wall strategy, where we always prefer right turns
  if (found_right)
    return 'R';
  else if (found_straight)
    return 'S';
  else if (found_left)
    return 'L';
  else
    return 'B';
}
void turn(char dir)
{
  // Perform turn based on direction parameter
  switch (dir)
  {
    case 'L':
      left(motor1, motor2, 200);
      qtra.readLineWhite(sensors1);
      while (sensors1[0] < thr[0])
      {
        qtra.readLineWhite(sensors1);  // Move left until sensor goes from white to black
      }
      qtra.readLineWhite(sensors1);
      left(motor1, motor2, 140);
      while (sensors1[0] > thr[0])
      {
        qtra.readLineWhite(sensors1);  // Continue left until back on white line
      }
      follow_segment1();  // Fast PID to quickly align bot on line
      brake(motor1, motor2);
      break;
      
    case 'R':
      right(motor1, motor2, 200);
      qtra.readLineWhite(sensors1);
      while (sensors1[7] < thr[7])
      {
        qtra.readLineWhite(sensors1);  // Move right until sensor goes from white to black
      }
      qtra.readLineWhite(sensors1);
      right(motor1, motor2, 140);
      while (sensors1[7] > thr[7])
      {
        qtra.readLineWhite(sensors1);  // Continue right until back on white line
      }
      follow_segment1();  // Fast PID to quickly align bot on line
      brake(motor1, motor2);
      break;
      
    case 'B':
      right(motor1, motor2, 150);
      qtra.readLineWhite(sensors1);
      while (sensors1[7] > thr[7])
      {
        qtra.readLineWhite(sensors1);  // U-turn using right turn
      }
      qtra.readLineWhite(sensors1);
      right(motor1, motor2, 120);
      while (sensors1[7] < thr[7])
      {
        qtra.readLineWhite(sensors1);
      }
      break;
  }
}
void follow_segment1()
{
  // Fast PID after turn to quickly align bot on line
  float Kp = 0.2;
  float Kd = 10;
  for (int j = 0; j < 10; j++)
  {
    int position = qtra.readLineWhite(sensors1);  // For BLACK line, use readLineBlack()
    int error = 3500 - position;
    int motorSpeed = Kp * error + Kd * (error - lastError);
    lastError = error;
    int rightMotorSpeed = BaseSpeed - motorSpeed;
    int leftMotorSpeed = BaseSpeed + motorSpeed;
    if (rightMotorSpeed > MaxSpeed) rightMotorSpeed = MaxSpeed;
    if (leftMotorSpeed > MaxSpeed) leftMotorSpeed = MaxSpeed;
    if (rightMotorSpeed < 0) rightMotorSpeed = 0;
    if (leftMotorSpeed < 0) leftMotorSpeed = 0;
    motor1.drive(rightMotorSpeed);
    motor2.drive(leftMotorSpeed);
    delay(1);
  }
}
void simplify_path()
{
  // Path simplification. The strategy is that whenever we encounter a
  // sequence xBx, we can simplify it by cutting out the dead end.

  if (path_length < 3 || path[path_length - 2] != 'B')      // simplify the path only if the second-to-last turn was a 'B'
    return;
  int total_angle = 0;
  int m;
  // Get the angle as a number between 0 and 360 degrees.
  for (m = 1; m <= 3; m++)
  {
    switch (path[path_length - m])
    {
      case 'R':
        total_angle += 90;
        break;
      case 'L':
        total_angle += 270;
        break;
      case 'B':
        total_angle += 180;
        break;
    }
  }
  // Replace all of those turns with a single one.
  total_angle = total_angle % 360;
  switch (total_angle)
  {
    case 0:
      path[path_length - 3] = 'S';
      break;
    case 90:
      path[path_length - 3] = 'R';
      break;
    case 180:
      path[path_length - 3] = 'B';
      break;
    case 270:
      path[path_length - 3] = 'L';
      break;
  }
  path_length -= 2;
}
void follow_segment2()
{
  // Backward moving PID
  int Kp = 1;
  int Kd = 200;
  int baseSpeed = 100;
  int maxSpeed = 100;
  for (int j = 0; j < 100; j++)
  {
    int position = qtra.readLineWhite(sensors1);  // For BLACK line, use readLineBlack()
    int error = 3500 - position;
    int motorSpeed = Kp * error + Kd * (error - lastError);
    lastError = error;
    int rightMotorSpeed = baseSpeed + motorSpeed;
    int leftMotorSpeed = baseSpeed - motorSpeed;
    if (rightMotorSpeed > maxSpeed) rightMotorSpeed = maxSpeed;
    if (leftMotorSpeed > maxSpeed) leftMotorSpeed = maxSpeed;
    if (rightMotorSpeed < 0) rightMotorSpeed = 0;
    if (leftMotorSpeed < 0) leftMotorSpeed = 0;
    motor1.drive(-rightMotorSpeed);
    motor2.drive(-leftMotorSpeed);
    delay(1);
  }
}

void follow_segment3()
{
  int Kp = 1;
  int Kd = 50;
  for (int j = 0; j < 10; j++)
  {
    int position = qtra.readLineWhite(sensors1);  // For BLACK line, use readLineBlack()
    int error = 3500 - position;
    int motorSpeed = Kp * error + Kd * (error - lastError);
    lastError = error;
    int rightMotorSpeed = BaseSpeed - motorSpeed;
    int leftMotorSpeed = BaseSpeed + motorSpeed;
    if (rightMotorSpeed > MaxSpeed) rightMotorSpeed = MaxSpeed;
    if (leftMotorSpeed > MaxSpeed) leftMotorSpeed = MaxSpeed;
    if (rightMotorSpeed < 0) rightMotorSpeed = 0;
    if (leftMotorSpeed < 0) leftMotorSpeed = 0;
    motor1.drive(rightMotorSpeed);
    motor2.drive(leftMotorSpeed);
    delay(1);
  }
}

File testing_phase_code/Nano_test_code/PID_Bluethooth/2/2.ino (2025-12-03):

#include <SparkFun_TB6612.h>
#include <QTRSensors.h>

// Motor pins
#define AIN1 8
#define BIN1 5
#define AIN2 9
#define BIN2 4
#define PWMA 6
#define PWMB 3
#define STBY 10

const int offsetA = 1;
const int offsetB = 1;

// Controls - REORGANIZED
#define SW_START 10      // SW1 - Start/Stop line following
#define SW_CALIBRATE 11  // SW2 - Calibration
#define LED 7

// Sensors
#define NUM_SENSORS 8
#define SENSOR_TIMEOUT 2500
unsigned int sensors1[NUM_SENSORS];
QTRSensors qtra;

// PID Parameters - Adjustable via Bluetooth
float kp = 0.5;
float ki = 0.0;
float kd = 10;

// Speed settings
int maxSpeed = 180;
int baseSpeed = 180;

// Line tracking
bool followBlackLine = false;
int centerPosition = 3500;

// PID variables
int lastError = 0;
float integral = 0.0;
float integral_limit = 3000.0;

// Turn detection - CHANGED TO VARIABLES INSTEAD OF CONST
int turnThreshold = 1000; // Error threshold for turn detection
unsigned long turnDuration = 800; // ms for 90 degree turn
int turnSpeed = 150; // Speed during turning

bool turnDetected = false;
unsigned long turnStartTime = 0;

// State management
enum State { IDLE, CALIBRATING, READY, RUNNING, TURNING };
State currentState = IDLE;

String btBuffer = "";

Motor motor1 = Motor(AIN1, AIN2, PWMA, offsetA, STBY);
Motor motor2 = Motor(BIN1, BIN2, PWMB, offsetB, STBY);

// ========== SETUP ==========
void setup() {
  // Pre-allocate buffer for better performance
  btBuffer.reserve(32);
  
  // Configure sensors
  qtra.setTypeAnalog();
  qtra.setSensorPins((const uint8_t[]) {A0, A1, A2, A3, A4, A5, A6, A7}, NUM_SENSORS);
  qtra.setTimeout(SENSOR_TIMEOUT);

  // Configure pins
  pinMode(SW_START, INPUT_PULLUP);
  pinMode(SW_CALIBRATE, INPUT_PULLUP);
  pinMode(LED, OUTPUT);

  // Initialize serial
  Serial.begin(9600);
  printWelcome();
  
  currentState = IDLE;
  blinkLED(2, 200);  // Ready indication
}

// ========== MAIN LOOP ==========
void loop() {
  checkBluetooth();
  
  static bool lastSW1 = HIGH;
  static bool lastSW2 = HIGH;
  bool sw1 = digitalRead(SW_START);
  bool sw2 = digitalRead(SW_CALIBRATE);
  
  // SW2 - Calibration (pressed)
  if (sw2 == LOW && lastSW2 == HIGH) {
    delay(50);  // Debounce
    if (digitalRead(SW_CALIBRATE) == LOW) {
      handleCalibration();
    }
  }
  
  // SW1 - Start/Stop (pressed)
  if (sw1 == LOW && lastSW1 == HIGH) {
    delay(50);  // Debounce
    if (digitalRead(SW_START) == LOW) {
      handleStartStop();
    }
  }
  
  // Execute current state
  if (currentState == RUNNING) {
    runLineFollowing();
  } else if (currentState == TURNING) {
    executeTurn();
  }
  
  lastSW1 = sw1;
  lastSW2 = sw2;
}

// ========== BUTTON HANDLERS ==========
void handleCalibration() {
  if (currentState == RUNNING || currentState == TURNING) {
    Serial.println("Stop robot before calibration!");
    blinkLED(3, 100);
    return;
  }
  
  currentState = CALIBRATING;
  calibration();
  currentState = READY;
}

void handleStartStop() {
  if (currentState == IDLE) {
    Serial.println("Calibrate first (press SW2)!");
    blinkLED(3, 100);
    return;
  }
  
  if (currentState == RUNNING || currentState == TURNING) {
    // Stop
    currentState = READY;
    brake(motor1, motor2);
    integral = 0;  // Reset integral
    turnDetected = false;
    Serial.println("STOPPED");
    blinkLED(1, 500);
  } else if (currentState == READY) {
    // Start
    currentState = RUNNING;
    Serial.println("STARTING...");
    blinkLED(2, 100);
    // Ramp start for smooth acceleration
    forward(motor1, motor2, 80);
    delay(100);
  }
}

// ========== CALIBRATION ==========
void calibration() {
  Serial.println("=== CALIBRATING ===");
  Serial.println("Move robot left-right over line...");
  digitalWrite(LED, HIGH);
  
  for (int i = 0; i <= 100; i++) {
    if (i < 25 || i >= 75) {
      left(motor1, motor2, 200);
    } else {
      right(motor1, motor2, 200);
    }
    qtra.calibrate();
    delay(10);
  }
  
  brake(motor1, motor2);
  digitalWrite(LED, LOW);
  Serial.println("Calibration Complete!");
  Serial.println("Press SW1 to start");
  blinkLED(2, 200);
}

// ========== TURN DETECTION & EXECUTION ==========
bool detectTurn(int error) {
  // Detect sharp turn when error exceeds threshold
  return abs(error) > turnThreshold;
}

void executeTurn() {
  // Check if turn duration completed
  if (millis() - turnStartTime >= turnDuration) {
    // Return to line following
    currentState = RUNNING;
    turnDetected = false;
    integral = 0; // Reset integral after turn
    Serial.println("Turn completed, resuming line following");
    return;
  }
  
  // Continue turning - one motor CW, other CCW
  // For right turns (positive error), turn right
  // For left turns (negative error), turn left
  
  if (lastError > 0) {
    // Right turn - motor1 forward, motor2 backward
    motor1.drive(turnSpeed);
    motor2.drive(-turnSpeed);
  } else {
    // Left turn - motor1 backward, motor2 forward
    motor1.drive(-turnSpeed);
    motor2.drive(turnSpeed);
  }
}

// ========== LINE FOLLOWING ==========
void runLineFollowing() {
  checkBluetooth();
  
  // Read sensor position
  int position = followBlackLine ? qtra.readLineBlack(sensors1) : qtra.readLineWhite(sensors1);
  
  // Calculate error
  int error = centerPosition - position;
  
  // Check for 90-degree turn
  if (detectTurn(error) && !turnDetected) {
    turnDetected = true;
    currentState = TURNING;
    turnStartTime = millis();
    Serial.println("90-degree turn detected! Executing turn...");
    return; // Exit line following to start turn
  }
  
  // If no turn detected, continue normal PID line following
  integral += error;
  integral = constrain(integral, -integral_limit, integral_limit);
  
  int derivative = error - lastError;
  lastError = error;
  
  float correction = kp * error + ki * integral + kd * derivative;
  correction = constrain(correction, -1000.0, 1000.0);
  
  int rightSpeed = constrain(baseSpeed - correction, 0, maxSpeed);
  int leftSpeed = constrain(baseSpeed + correction, 0, maxSpeed);
  
  motor1.drive(rightSpeed);
  motor2.drive(leftSpeed);
}

// ========== BLUETOOTH PROCESSING ==========
void checkBluetooth() {
  while (Serial.available()) {
    char c = Serial.read();
    
    if (c == '\n' || c == '\r') {
      if (btBuffer.length() > 0) {
        processCommand(btBuffer);
        btBuffer = "";
      }
    } else if (btBuffer.length() < 31) {  // Prevent overflow
      btBuffer += c;
    }
  }
}
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

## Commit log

2025-09-27 feat: ESP32 line follower with PID control and multi-sensor support
2025-11-13 Datasheet ESP32
2025-11-19 Uploaded correct motor driver datasheet
2025-11-25 Added linefollower code with wireless PID tuning
2025-11-27 Added plotter for PID variable
2025-12-03 Added ESP32 based PCB Design
    [DM-OLED096-636--3DModel-STEP-56544.STEP, DM-OLED096-636.step, lineMazeSolver.kicad_pcb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]
2025-12-04 Added Line Maze Solver Code for Arduino NANO
2025-12-04 Edited Design
    [lineMazeSolver.kicad_pcb]
2025-12-10 Resolved maze solving logic
    [main.cpp]
2025-12-10 Added PCB Design for Arduino nano
    [DM-OLED096-636--3DModel-STEP-56544.STEP, DM-OLED096-636.step, kikad_dsign.kicad_pcb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]
2025-12-10 Added a new features with NANO Based pcb PCB
    [DM-OLED096-636--3DModel-STEP-56544.STEP, DM-OLED096-636.step, kikad_dsign.kicad_pcb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]
2026-01-16 Renamed and Rearranged files.
    [DM-OLED096-636--3DModel-STEP-56544.STEP, DM-OLED096-636.step, kikad_dsign.kicad_pcb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]
